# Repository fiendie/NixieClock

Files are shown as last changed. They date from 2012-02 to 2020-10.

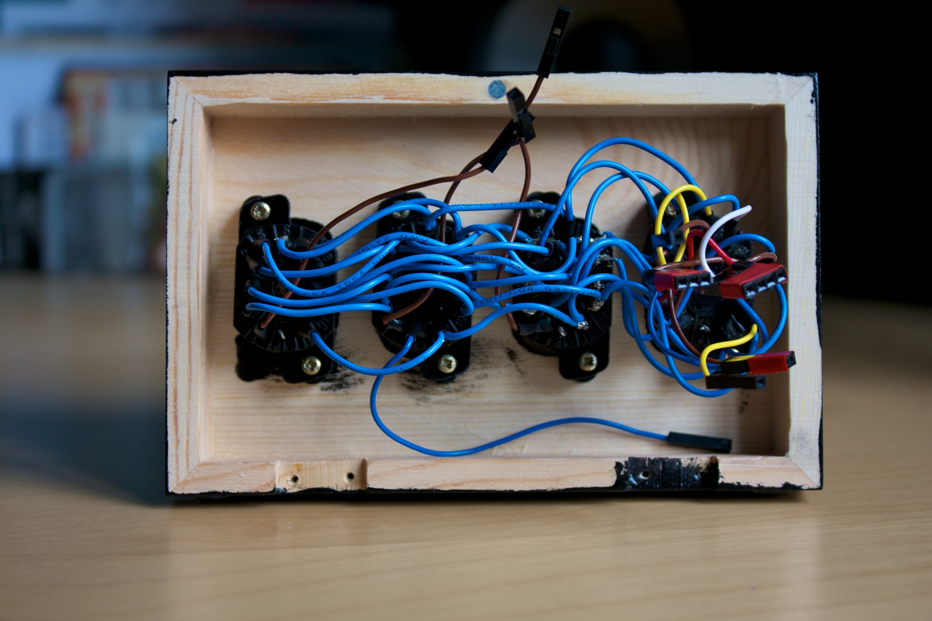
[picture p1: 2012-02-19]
images/wiring.jpg

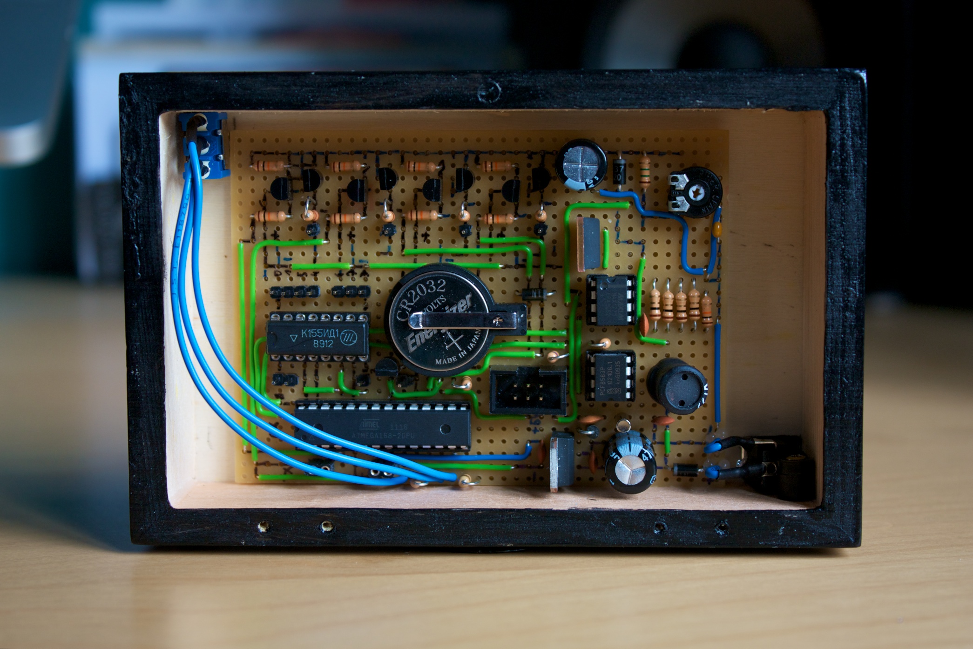
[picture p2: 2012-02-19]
images/circuit.jpg

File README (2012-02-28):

This Arduino Sketch controls a NIXIE clock with 4 tubes. 
I used a plain ATMega168 microcontroller instead of an Arduino board for obvious reasons.
Here is a picture of the circuit board: https://github.com/fiendie/NixieClock/raw/master/images/circuit.jpg

I am using a DS1307 RTC chip to keep track of the time. 

The schematics can be found here: https://github.com/fiendie/NixieClock/tree/master/schematics

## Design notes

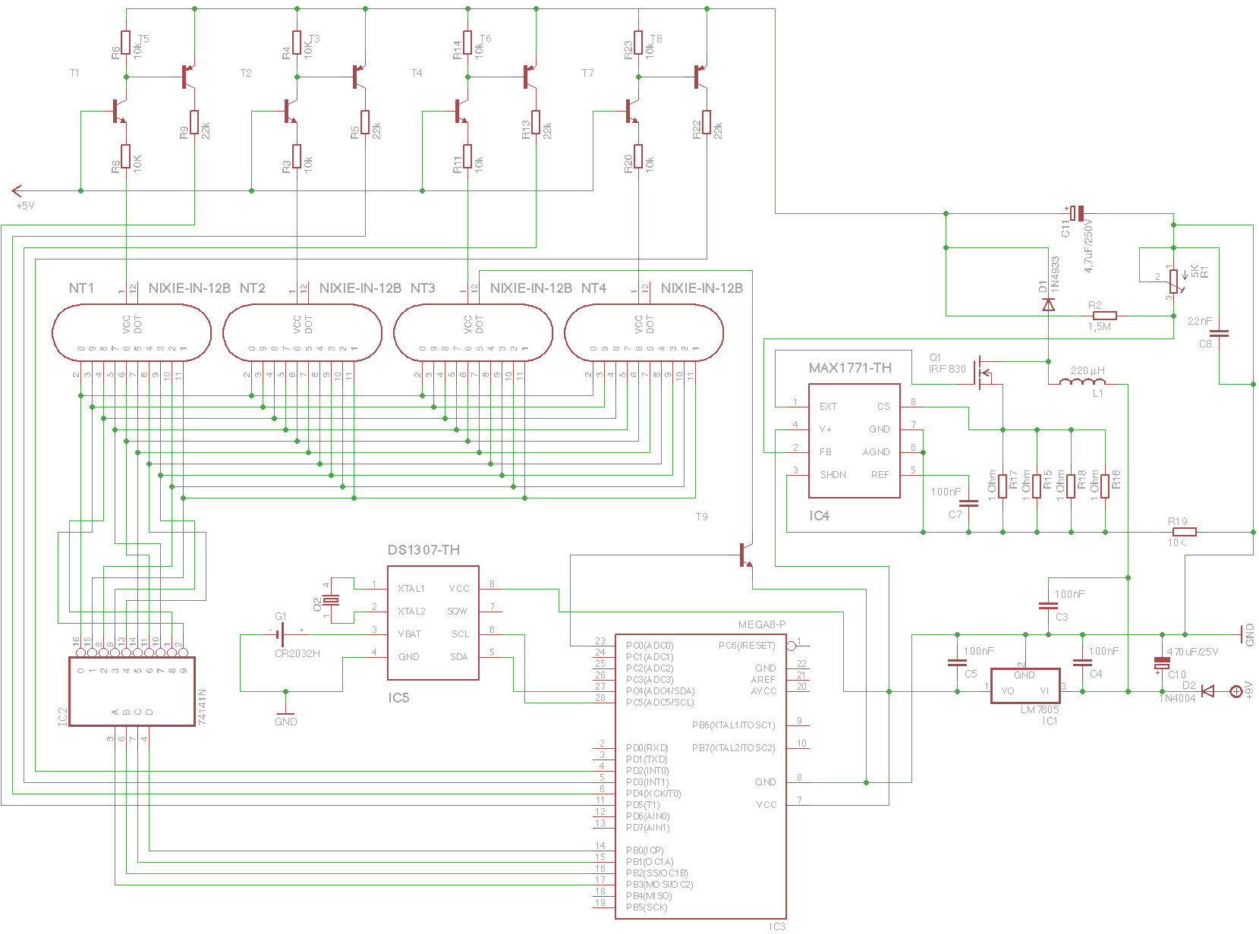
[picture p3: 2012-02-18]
schematics/nixie_clock.png

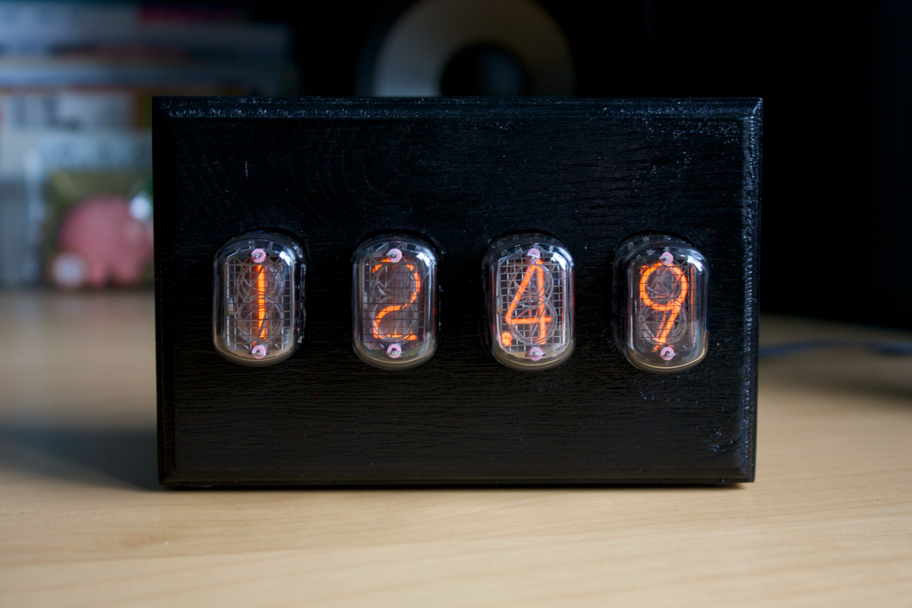
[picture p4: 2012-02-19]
images/front.jpg

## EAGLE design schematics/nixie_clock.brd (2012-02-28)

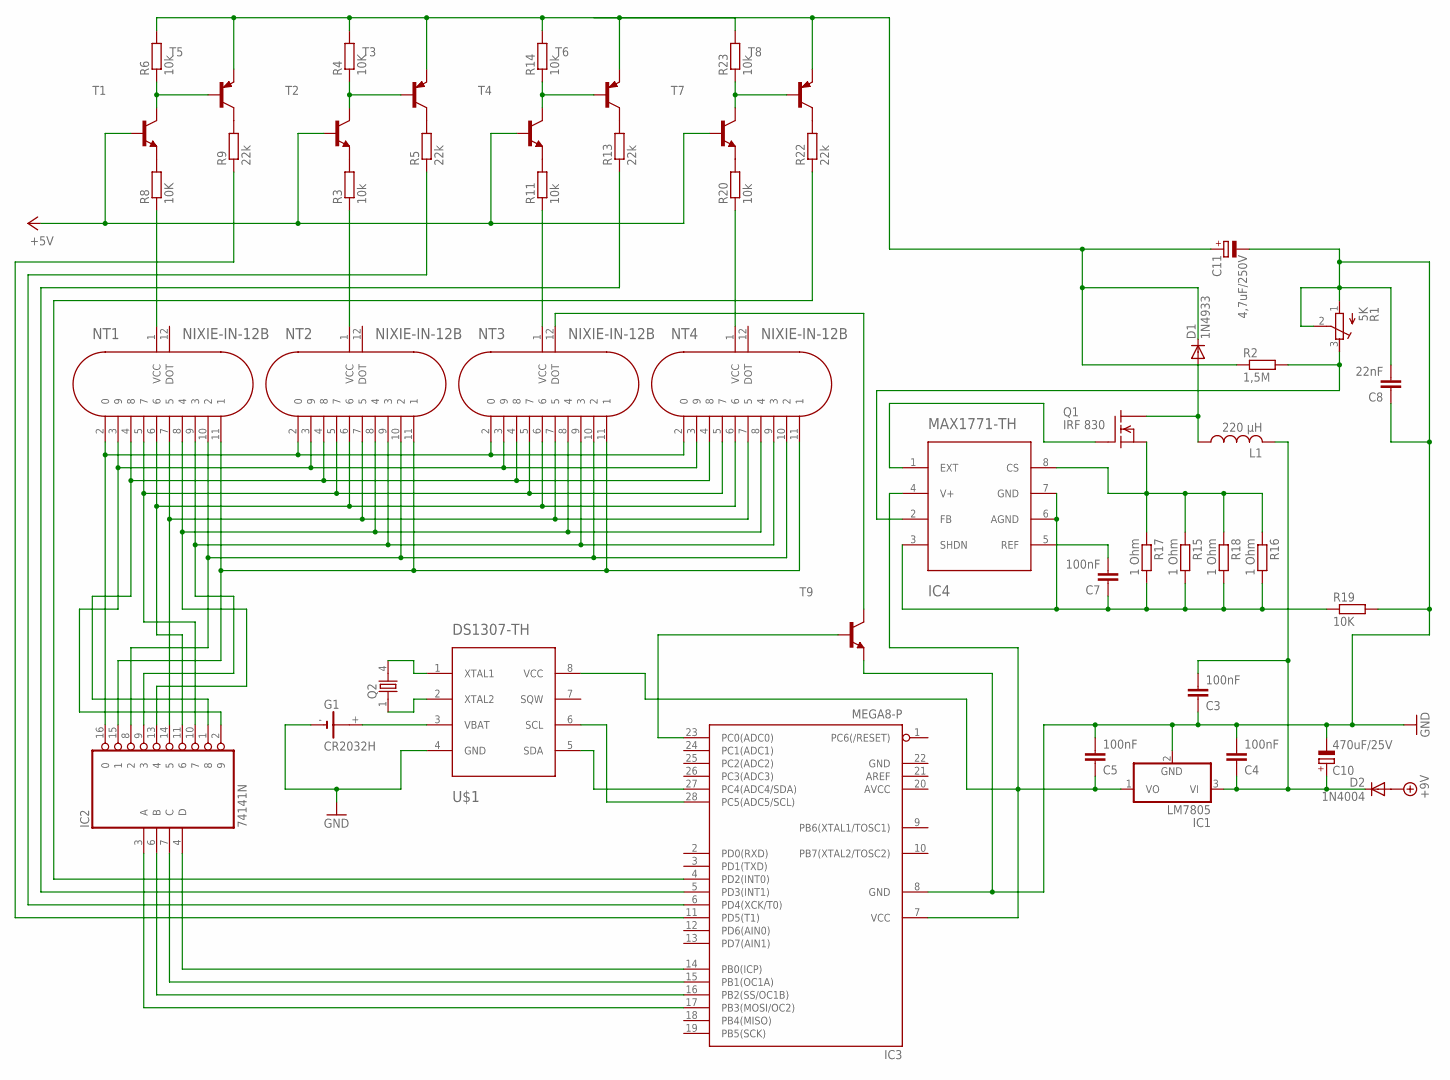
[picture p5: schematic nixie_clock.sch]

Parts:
C3, C4, C5, C7: 100nF; C5B2.5
C8: 22nF; C5B2.5
C10: 470uF/25V; E2,5-6E
C11: 4,7uF/250V; E2,5-6E
D1: 1N4933; DO41-10
D2: 1N4004; DO41-10
G1: CR2032H
IC1: LM7805; TO92
IC2: 74141N; DIL16
IC3: MEGA8-P; DIL28-3
IC4: MAX1771-TH; MAX1771
L1: 220 µH; TJ4-U2
NT1, NT2, NT3, NT4: NIXIE-IN-12B; NIXIE
Q1: IRF 830; TO220
Q2: 86SMX
R1: 5K; RTRIM4G/J
R2: 1,5M; 0207/10
R3, R6, R11, R14, R20, R23: 10k; 0207/10
R4, R8, R19: 10K; 0207/10
R5, R9, R13, R22: 22k; 0207/10
R15, R16, R17, R18: 1 Ohm; 0207/10
T1, T2, T4, T7, T9: MPSA44-NPN-TO92-CBE; TO92-CBE
T3, T5, T6, T8: MPSA64-PNP-TO92-CBE; TO92-CBE
U$1: DS1307-TH; DS1307

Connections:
+5V: T1.B, T2.B, T4.B, T7.B
+9V: D2.A
AVCC: IC3.20 (AVCC)
GND: C3.1, C4.2, C5.2, C8.1, C8.2, C10.-, C11.-, G1.-, IC1.2 (GND), IC2.12 (GND), IC3.8 (GND), IC3.22 (GND), R1.1 (E), R1.2 (S), R19.2, T9.E, U$1.4 (GND)
IC5: Q2.1, U$1.2 (XTAL2)
MAX1771: IC4.1 (EXT), Q1.1 (G)
unnamed: R6.1, T1.C, T5.B
unnamed: R4.1, T2.C, T3.B
unnamed: R9.2, T5.C
unnamed: IC4.2 (FB), R1.3 (A), R2.2
unnamed: R14.1, T4.C, T6.B
unnamed: R5.2, T3.C
unnamed: R23.1, T7.C, T8.B
unnamed: R13.2, T6.C
unnamed: R22.2, T8.C
unnamed: R8.2, T1.E
unnamed: R3.2, T2.E
unnamed: R11.2, T4.E
unnamed: R20.2, T7.E
unnamed: IC2.16 (0), NT1.2 (0), NT2.2 (0), NT3.2 (0), NT4.2 (0)
unnamed: C11.+, D1.C, R2.1, T8.E
unnamed: IC2.8 (2), NT1.10 (2), NT2.10 (2), NT3.10 (2), NT4.10 (2)
unnamed: IC2.9 (3), NT1.9 (3), NT2.9 (3), NT3.9 (3), NT4.9 (3)
unnamed: IC2.13 (4), NT1.8 (4), NT2.8 (4), NT3.8 (4), NT4.8 (4)
unnamed: NT2.1 (VCC), R3.1
unnamed: NT3.1 (VCC), R11.1
unnamed: NT4.1 (VCC), R20.1
unnamed: IC3.11 (PD5(T1)), R9.1
unnamed: D1.A, L1.1, Q1.2 (D)
unnamed: C5.1, IC1.1 (VO), IC3.7 (VCC), IC4.4 (V+), U$1.8 (VCC)
unnamed: IC4.8 (CS), Q1.3 (S), R15.1, R16.1, R17.1, R18.1
unnamed: IC3.6 (PD4(XCK/T0)), R5.1
unnamed: IC3.5 (PD3(INT1)), R13.1
unnamed: C7.2, IC4.5 (REF)
unnamed: C3.2, C4.1, C10.+, D2.C, IC1.3 (VI), L1.2
unnamed: IC3.4 (PD2(INT0)), R22.1
unnamed: IC2.14 (5), NT1.7 (5), NT2.7 (5), NT3.7 (5), NT4.7 (5)
unnamed: IC2.11 (6), NT1.6, NT2.6, NT3.6, NT4.6
unnamed: IC2.10 (7), NT1.5 (7), NT2.5 (7), NT3.5 (7), NT4.5 (7)
unnamed: IC2.1 (8), NT1.4 (8), NT2.4 (8), NT3.4 (8), NT4.4 (8)
unnamed: IC2.2 (9), NT1.3 (9), NT2.3 (9), NT3.3 (9), NT4.3 (9)
unnamed: IC2.4 (D), IC3.14 (PB0(ICP))
unnamed: IC2.7 (C), IC3.15 (PB1(OC1A))
unnamed: IC2.6 (B), IC3.16 (PB2(SS/OC1B))
unnamed: IC2.3 (A), IC3.17 (PB3(MOSI/OC2))
unnamed: IC3.27 (PC4(ADC4/SDA)), U$1.5 (SDA)
unnamed: IC3.28 (PC5(ADC5/SCL)), U$1.6 (SCL)
unnamed: IC2.15 (1), NT1.11 (1), NT2.11 (1), NT3.11 (1), NT4.11 (1)
unnamed: R4.2, R6.2, R14.2, R23.2, T3.E, T5.E, T6.E
unnamed: Q2.4 (2), U$1.1 (XTAL1)
unnamed: C7.1, IC4.3 (SHDN), IC4.6 (AGND), IC4.7 (GND), R15.2, R16.2, R17.2, R18.2, R19.1
unnamed: G1.+, U$1.3 (VBAT)
unnamed: NT3.12 (DOT), T9.C
unnamed: IC3.23 (PC0(ADC0)), T9.B
NT1: NT1.1 (VCC), R8.1
VCC: IC2.5 (VCC)

Board: 2 copper layers, 50 parts (0 on the bottom side), 53 nets, no tracks yet.

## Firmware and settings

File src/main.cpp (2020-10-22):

/**
 * NixieClock 
 * 
 * An Arduino Sketch for multiplexing 4 NIXIE tubes to show the 
 * current time.
 * The time is read from a DS1307 RTC chip. 
 * 
 * by Andreas Tacke (at@mail.fiendie.net).
 *
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
 * You should have received a copy of the GNU General Public License along
 * with this program; if not, write to the Free Software Foundation, Inc.,
 * 51 Franklin Street, Fifth Floor, Boston, MA 02110-1301 USA.
 */

// Increase i2C frequency
// #ifndef TWI_FREQ
// #define TWI_FREQ 100000L
// #endif

#include <Arduino.h>

#include <Wire.h>
#include <stdio.h>
#include <avr/wdt.h>

#include <Bounce2.h>

#include "RTClib.h"

#define SHOW_TIME 0
#define SHOW_DATE 1
#define SHOW_YEAR 2

#define N_NIXIES 4

// Pin assignments
#define NIXIE1 2
#define NIXIE2 3
#define NIXIE3 13
#define NIXIE4 12

#define DECIMAL 9

#define BIT_A A2
#define BIT_B A0
#define BIT_C A1
#define BIT_D A3

#define NUM_BUTTONS 3

// 5 = Up, 6 = Down, 8 = Mode
const uint8_t BUTTON_PINS[NUM_BUTTONS] = {8, 5, 6};

Bounce *buttons = new Bounce[NUM_BUTTONS];

RTC_DS1307 rtc;
DateTime dt;

static const uint8_t nixies[N_NIXIES] = {NIXIE1, NIXIE2, NIXIE3, NIXIE4};
static const uint8_t bits[4] = {BIT_A, BIT_B, BIT_C, BIT_D};

static const uint8_t nums[10][4] = {
    {0, 0, 0, 0}, {1, 0, 0, 0}, {0, 1, 0, 0}, {1, 1, 0, 0}, {0, 0, 1, 0}, {1, 0, 1, 0}, {0, 1, 1, 0}, {1, 1, 1, 0}, {0, 0, 0, 1}, {1, 0, 0, 1}};

// The values that are currently being displayed
static volatile uint8_t nixie_val[N_NIXIES] = {0};

// The values that are actually to be displayed in the end
static uint8_t nixie_set[N_NIXIES] = {0};

static volatile uint8_t time_passed = 1;

// Position of the number in the tube
static const uint8_t nixie_level[10 + 1] = {
    10, 1, 2, 6, 7, 5, 0, 4, 9, 8, 3};

static const uint8_t animation_speed = 10;
static volatile uint8_t animation_step = 0;

static uint8_t mode = 0;

static uint8_t cur_sec = 0;
static uint8_t cnt = 0;

static uint8_t active_nixie = 0;

static void setNixieNum(uint8_t num)
{
  uint8_t i;
  for (i = 0; i < 4; i++)
  {
    digitalWrite(bits[i], nums[num][i]);
  }
}

static void updateNixies(void)
{
  uint8_t i;
  for (i = 0; i < 4; i++)
  {
    digitalWrite(nixies[i], HIGH);
  }

  setNixieNum(nixie_val[active_nixie]);
  digitalWrite(nixies[active_nixie], LOW);

  active_nixie++;
  active_nixie %= 4;
}

static uint8_t modAdd(int8_t value, int8_t diff, int8_t v_max)
{
  if (diff < 0)
  {
    return (value + v_max + diff) % v_max;
  }
  if (diff > 0)
  {
    return (value + diff) % v_max;
  }

  return 0;
}

static void adjustTime(int8_t v)
{
  dt = rtc.now();

  int hour = dt.hour();
  int minute = dt.minute();

  if (v > 0)
  {
    if (dt.minute() == 59)
    {
      hour = modAdd(dt.hour(), 1, 24);
    }
    minute = modAdd(dt.minute(), 1, 60);
  }
  else if (v < 0)
  {
    if (dt.minute() == 0)
    {
      hour = modAdd(dt.hour(), -1, 24);
    }
    minute = modAdd(dt.minute(), -1, 60);
  }

  rtc.adjust(DateTime(dt.year(), dt.month(), dt.day(), hour, minute, 0));
}

static void refreshNixieVals(void)
{
  switch (mode)
  {
  case SHOW_TIME:
    nixie_set[0] = dt.hour() / 10;
    nixie_set[1] = dt.hour() % 10;
    nixie_set[2] = dt.minute() / 10;
    nixie_set[3] = dt.minute() % 10;
    break;
  case SHOW_DATE:
    nixie_set[0] = dt.day() / 10;
    nixie_set[1] = dt.day() % 10;
    nixie_set[2] = dt.month() / 10;
    nixie_set[3] = dt.month() % 10;
    break;
  case SHOW_YEAR:
    nixie_set[0] = 2;
    nixie_set[1] = 0;
    nixie_set[2] = dt.year() % 1000 / 10;
    nixie_set[3] = dt.year() % 10;
    break;
  }
}

static uint8_t get_level(uint8_t v)
{
  uint8_t l = sizeof(nixie_level);
  
  while (--l && nixie_level[l] != v)
  {
  }
  return l;
}

static void animate(void)
{
  uint8_t i = 0;
  uint8_t cl = 0;
  uint8_t tl = 0;

  for (i = 0; i < N_NIXIES; i++)
  {
    cl = get_level(nixie_val[i]);
    tl = get_level(nixie_set[i]);

    if (cl > tl)
    {
      // Move down a level
      nixie_val[i] = nixie_level[cl - 1];
    }
    else if (cl < tl)
    {
      nixie_val[i] = nixie_level[cl + 1];
    }
  }
}

void setup(void)
{
  // TIMER 1 for interrupt frequency 500 Hz:
  cli();      
  
  TCCR1A = 0; 
  TCCR1B = 0; 
  TCNT1 = 0;

  // Set compare match register for 500 Hz increments
  // 31999 = 16000000 / (1 * 500) - 1 (must be <65536)
  OCR1A = 31999; 
  
  // Turn on CTC mode
  TCCR1B |= (1 << WGM12);
  
  // Set CS12, CS11 and CS10 bits for 1 prescaler
  TCCR1B |= (0 << CS12) | (0 << CS11) | (1 << CS10);
  
  // Enable timer compare interrupt
  TIMSK1 |= (1 << OCIE1A);

  sei();

  // Enable watchdog timer with a 1 second time-out
  wdt_enable(WDTO_1S);

  pinMode(NIXIE1, OUTPUT);
  pinMode(NIXIE2, OUTPUT);
  pinMode(NIXIE3, OUTPUT);
  pinMode(NIXIE4, OUTPUT);

  pinMode(DECIMAL, OUTPUT);

  pinMode(BIT_A, OUTPUT);
  pinMode(BIT_B, OUTPUT);
  pinMode(BIT_C, OUTPUT);
  pinMode(BIT_D, OUTPUT);

  for (int i = 0; i < NUM_BUTTONS; i++)
  {
    // Set up the bounce instance for the current button
    buttons[i].attach(BUTTON_PINS[i], INPUT);

    // Interval in ms
    buttons[i].interval(50);
  }

  rtc.begin();
  // rtc.adjust(DateTime(2020, 10, 22, 9, 3, 0));
}

void loop(void)
{
  // Woof woof!
  wdt_reset();

  for (int i = 0; i < NUM_BUTTONS; i++)
  {
    // Update the Bounce instance :
    buttons[i].update();
  }

  // If it fell, flag the need to toggle the LED
  if (buttons[0].rose())
  {
    mode++;
    mode %= 3;
    refreshNixieVals();
  }
  else if (buttons[1].rose())
  {
    adjustTime(1);
    refreshNixieVals();
  }
  else if (buttons[2].rose())
  {
    adjustTime(-1);
    refreshNixieVals();
  }

  if (time_passed == 1)
  {
    cnt++;

    if (cnt == 1)
    {
      dt = rtc.now();
      refreshNixieVals();
    }

    cnt %= 100;
    time_passed = 0;
  }

  if (dt.second() != cur_sec)
  {
    cur_sec = dt.second();

    if (mode == SHOW_TIME)
    {
      digitalWrite(DECIMAL, (cur_sec % 2));
    }
  }

  switch (mode)
  {
  case SHOW_DATE:
    digitalWrite(DECIMAL, HIGH);
    break;
  case SHOW_YEAR:
    digitalWrite(DECIMAL, LOW);
    break;
  }

  if (animation_step)
  {
    animate();
    animation_step = 0;
  }
}

ISR(TIMER1_COMPA_vect)
{
  updateNixies();

  static uint8_t count = 0;
  if (count++ >= animation_speed)
  {
    animation_step = 1;
    count = 0;
  }

  time_passed = 1;
}

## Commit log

2012-02-05 Removed the PCF8583 dependency, added animation
    I exchanged the PCF8583 chip with a DS1307 because it has a dedicated
    battery input pin and because the PCF8583 seemed to be inaccurate. But
    that turned out to be a problem with the interference from the NIXIE
    power supply (which I still haven't resolved).
    [NixieClock.pde]
2012-02-11 Added a watchdog timer for extra reliability
2012-02-18 Added Schematics
    [nixie_clock.brd, nixie_clock.sch]
2012-02-28 Updated Schematics
    [nixie_clock.brd, nixie_clock.sch]
2012-03-02 Arduino 1.0 compatibility
2012-03-05 Arduino 1.0 Compatibility Fixes

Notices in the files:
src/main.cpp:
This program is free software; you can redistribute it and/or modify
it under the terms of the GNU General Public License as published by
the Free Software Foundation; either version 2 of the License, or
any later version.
